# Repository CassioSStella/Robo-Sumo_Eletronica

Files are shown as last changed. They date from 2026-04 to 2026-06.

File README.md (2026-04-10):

markdown# 🤖 PatoBots — Eletrônica do Robô de Sumô

Repositório da seção de eletrônica para o desenvolvimento de um robô de sumô híbrido de 500g,
desenvolvido como atividade de trainee da equipe **PatoBots**.

---

## 📋 Sobre o Projeto

O projeto consiste no desenvolvimento do hardware eletrônico do robô, incluindo esquemáticos
e layout de PCB produzidos no **KiCad**. A especificação completa do projeto está disponível
na documentação da equipe no Notion:

🔗 [Projeto de Integração Trainees PatoBots — Sumô Híbrido 500g](https://www.notion.so/Projeto-de-Integra-o-Trainees-PatoBots-Desenvolvimento-de-Sum-H-brido-500g-327fba90dc5980c68d72c41331cd149f)

## 🚀 Como Começar

### Configuração do KiCad
Caso não tenha experiência com o KiCad, recomenda-se seguir a playlist introdutória:

🎬 [Playlist — Introdução ao KiCad](https://www.youtube.com/watch?v=tVLF8Y9jc6o&list=PL8kCnofYYWZrkhUis1svLGux1tjYNJy2Z)

### Importando componentes do SnapEDA
Para adicionar os modelos de símbolos e footprints baixados do SnapEDA ao KiCad:

🎬 [Como configurar arquivos do SnapEDA no KiCad](https://www.youtube.com/watch?v=W9cLnIjvybo)

---

## 📌 Referências

| Recurso | Descrição |
|---|---|
| [Dory — Project Neon](https://github.com/project-neon/Dory) | Robô de sumô com eletrônica feita em KiCad, usado como referência comparativa. Os modelos KiCad do Kit ESP32 Doit foram obtidos deste repositório. |

---

## 🛠️ Ferramentas Utilizadas

- [KiCad](https://www.kicad.org/) — EDA para esquemáticos e PCB
- [SnapEDA](https://www.snapeda.com/) — Biblioteca de componentes

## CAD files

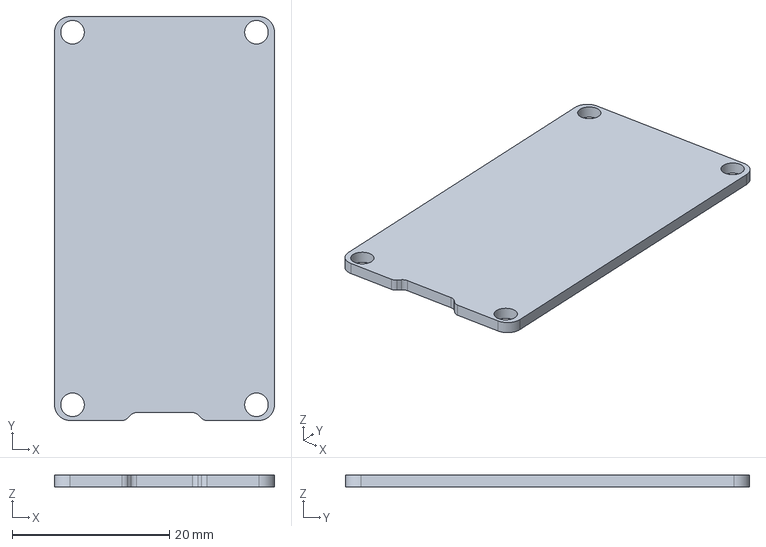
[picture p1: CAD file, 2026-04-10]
Recursos_Kicad/esp32_devkit_v1_doit.step
28.0 x 51.4 x 1.50 mm

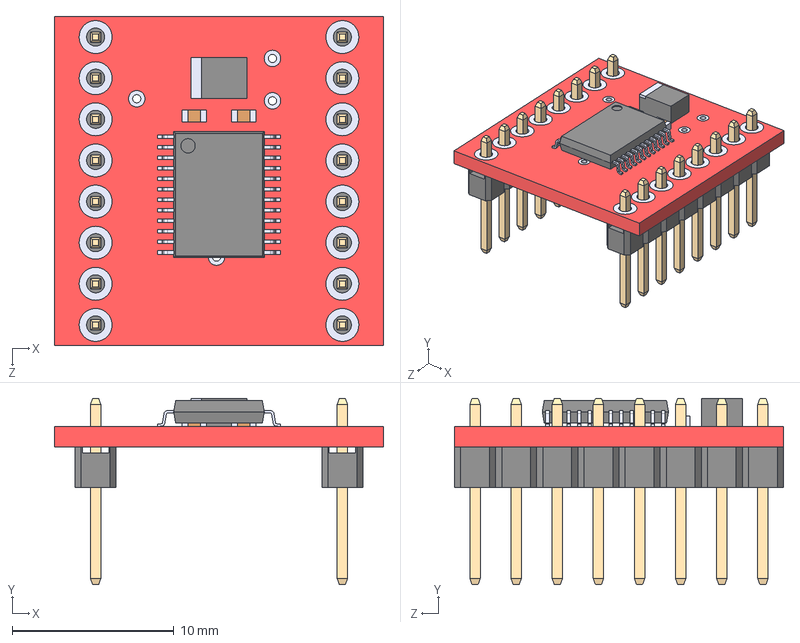
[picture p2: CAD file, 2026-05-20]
Recursos_Kicad/ROB-14450/ROB-14450--3DModel-STEP-418109.STEP
20.3 x 11.5 x 20.3 mm

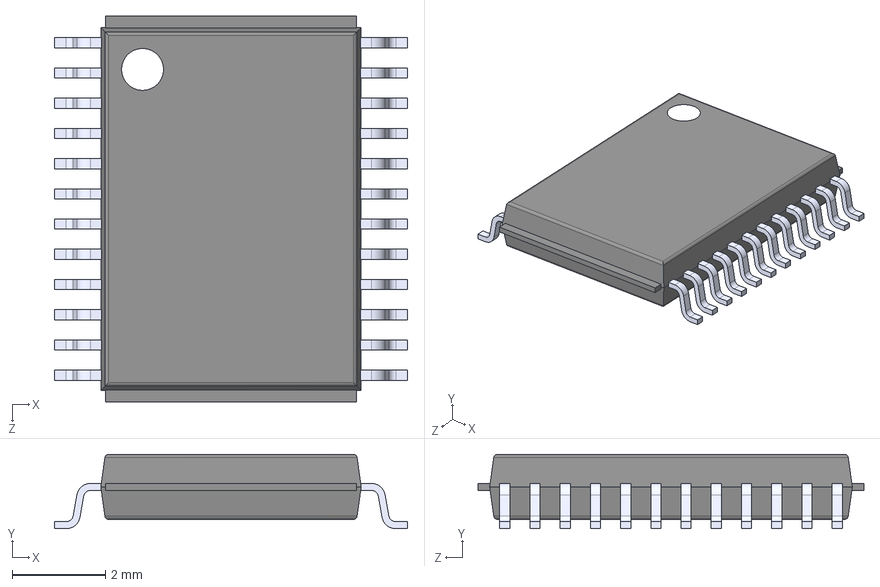
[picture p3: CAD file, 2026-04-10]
Recursos_Kicad/TB6612FNG_C_8_EL/TB6612FNG_C_8_EL.step
7.60 x 1.60 x 8.30 mm

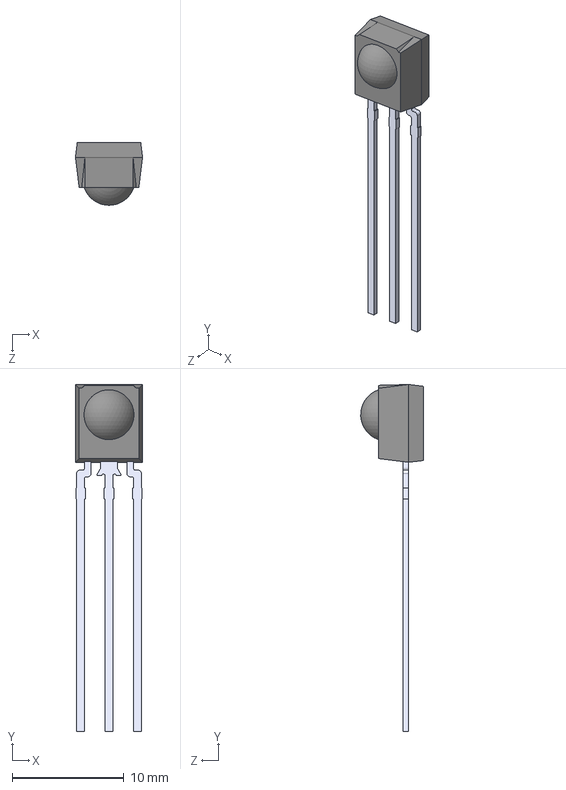
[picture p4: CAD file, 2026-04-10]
Recursos_Kicad/TSOP1838/TSOP1838.step
6.00 x 31.0 x 5.59 mm

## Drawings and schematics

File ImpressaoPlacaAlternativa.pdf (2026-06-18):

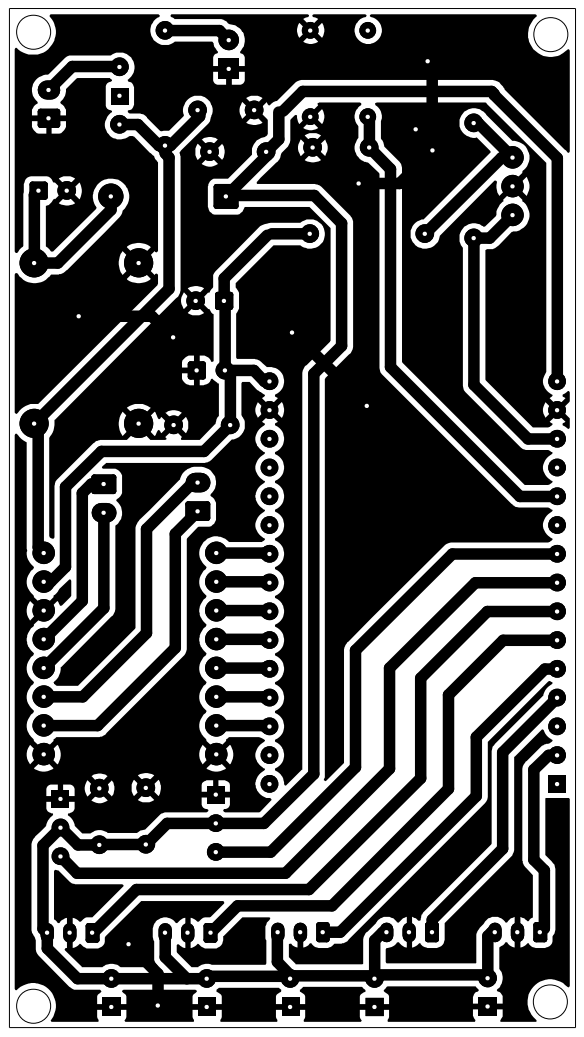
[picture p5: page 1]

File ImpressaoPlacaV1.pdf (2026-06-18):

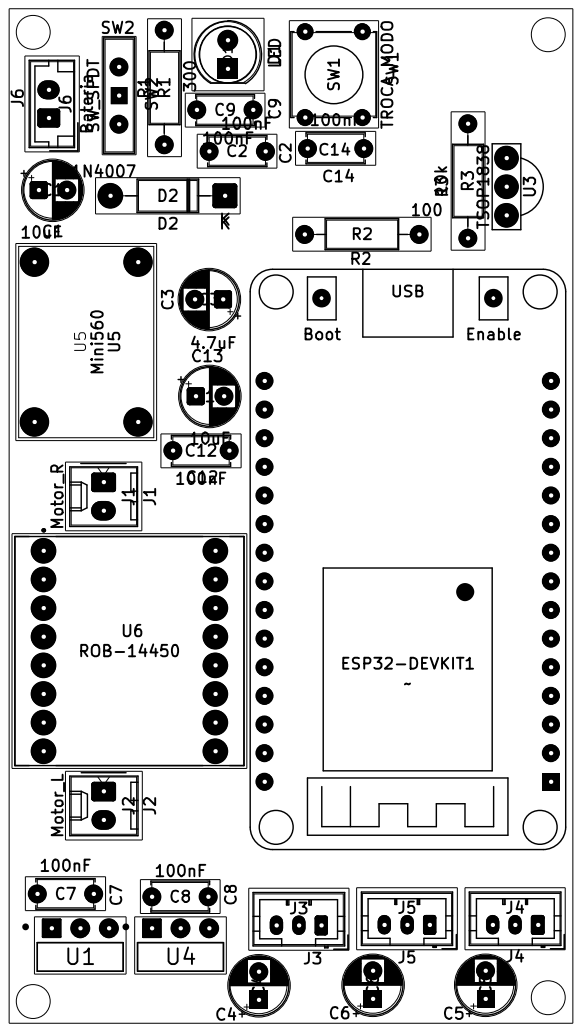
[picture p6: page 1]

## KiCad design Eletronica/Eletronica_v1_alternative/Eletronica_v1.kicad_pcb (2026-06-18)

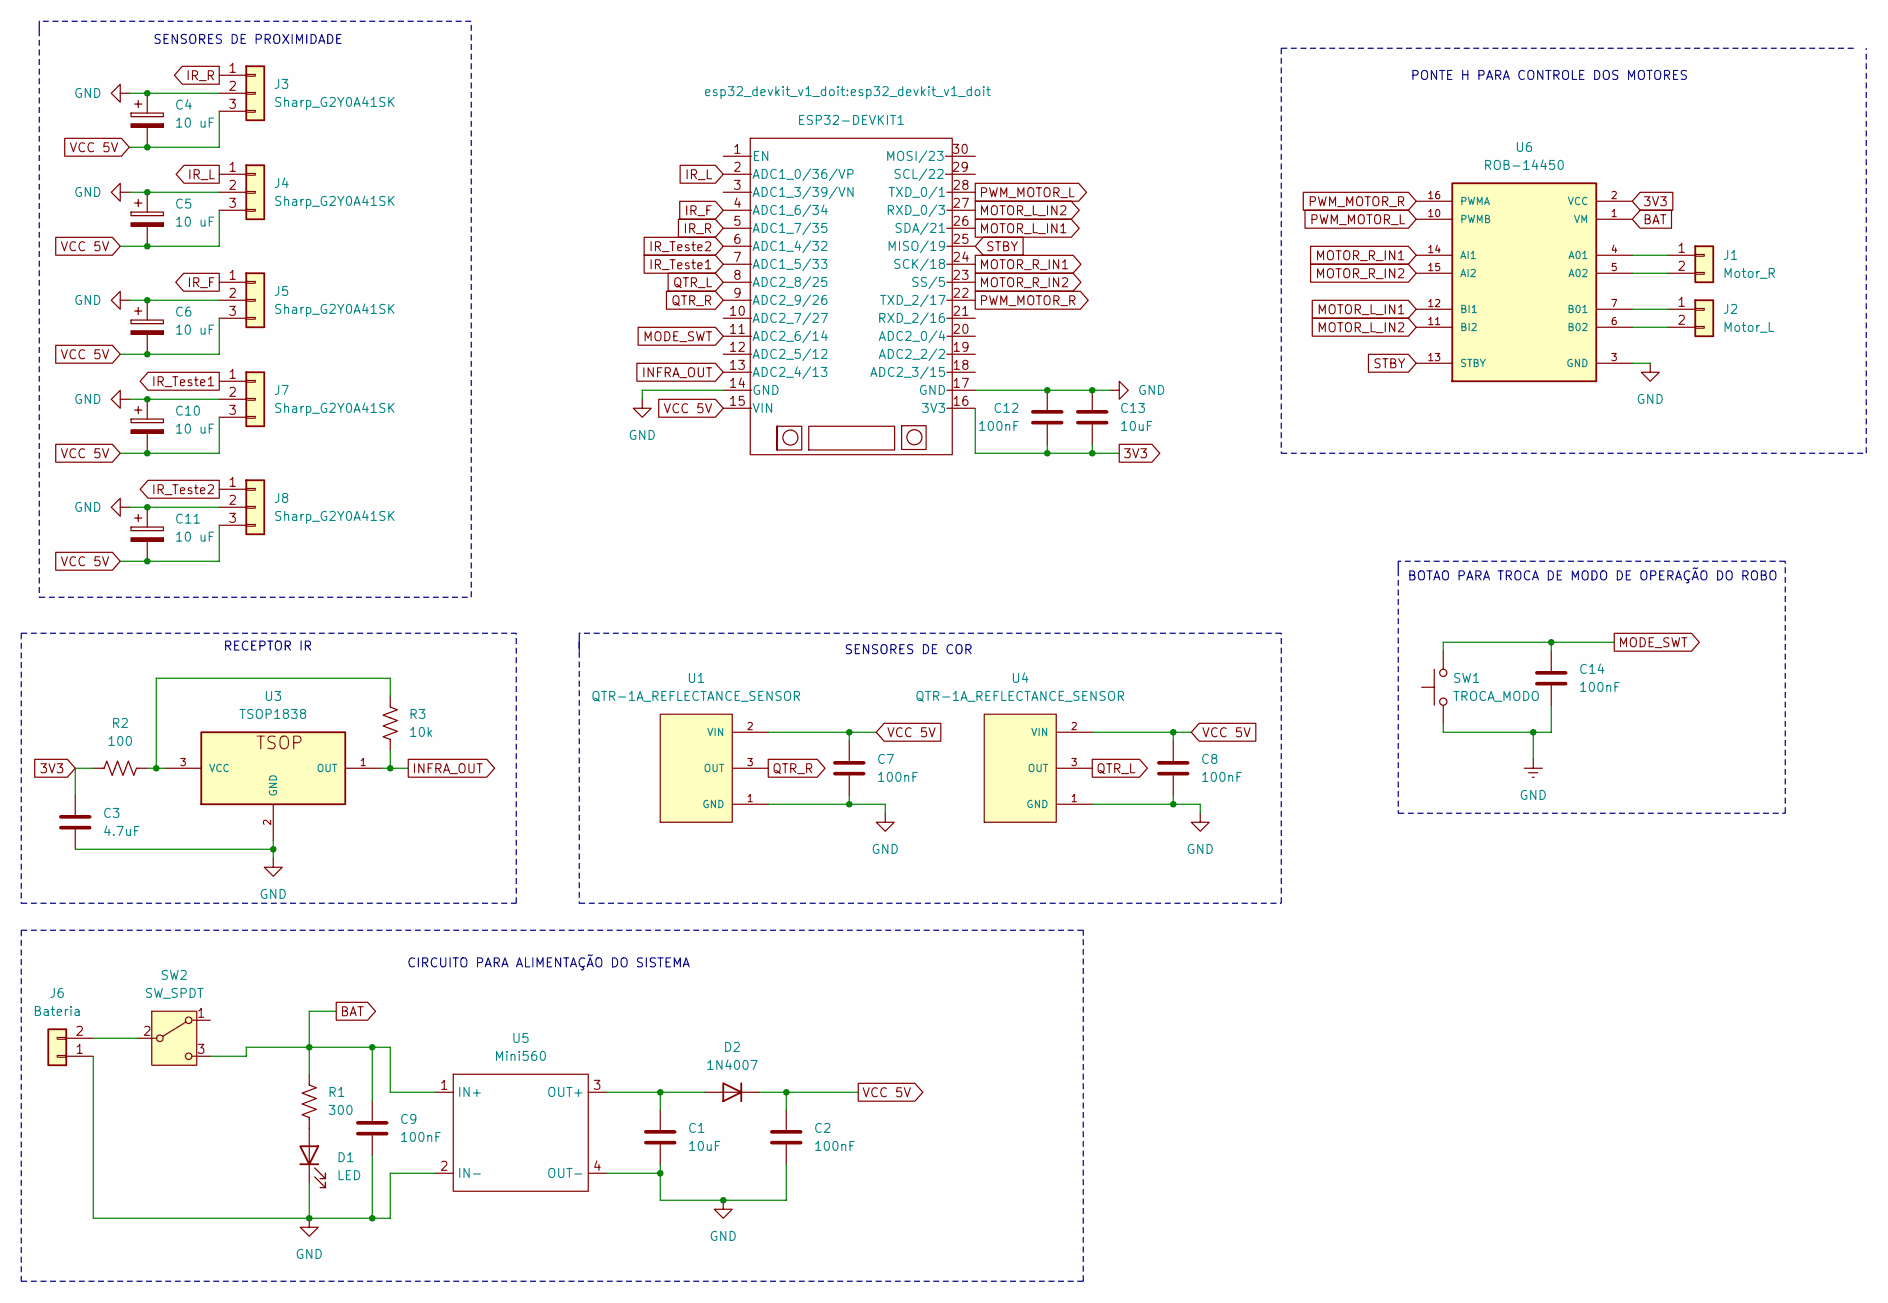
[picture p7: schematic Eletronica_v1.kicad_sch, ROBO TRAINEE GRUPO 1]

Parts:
C1, C13: 10uF; CP_Radial_D5.0mm_P2.50mm
C2, C7, C8, C9, C12, C14: 100nF; C_Disc_D5.0mm_W2.5mm_P5.00mm
C3: 4.7uF; CP_Radial_D5.0mm_P2.50mm
C4, C5, C6, C10, C11: 10 uF; CP_Radial_D5.0mm_P2.50mm
D1: LED; LED_D5.0mm
D2: 1N4007; D_DO-41_SOD81_P10.16mm_Horizontal
ESP32-DEVKIT1: esp32_devkit_v1_doit
J1: Motor_R; Molex_KK-254_AE-6410-02A_1x02_P2.54mm_Vertical
J2: Motor_L; Molex_KK-254_AE-6410-02A_1x02_P2.54mm_Vertical
J3, J4, J5, J7, J8: Sharp_G2Y0A41SK; JST_PH_B3B-PH-K_1x03_P2.00mm_Vertical
J6: Bateria; JST_EH_B2B-EH-A_1x02_P2.50mm_Vertical
R1: 300; R_Axial_DIN0207_L6.3mm_D2.5mm_P10.16mm_Horizontal
R2: 100; R_Axial_DIN0207_L6.3mm_D2.5mm_P10.16mm_Horizontal
R3: 10k; R_Axial_DIN0207_L6.3mm_D2.5mm_P10.16mm_Horizontal
SW1: TROCA_MODO; SW_Tactile_Straight_KSA0Axx1LFTR
SW2: SW_SPDT; SW_Slide-03_Wuerth-WS-SLTV_10x2.5x6.4_P2.54mm
U1, U4: QTR-1A_REFLECTANCE_SENSOR; SENSOR_QTR-1A_REFLECTANCE_SENSOR
U3: TSOP1838
U5: Mini560; Sem título
U6: ROB-14450; MODULE_ROB-14450; PARTREV 11-13-17

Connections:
3V3: C3.1, C12.2, C13.2, ESP32-DEVKIT1.16 (3V3), R2.1, U6.2 (VCC)
BAT: C9.1, R1.1, SW2.3 (C), U5.1 (IN+), U6.1 (VM)
GND: C1.2, C2.2, C3.2, C4.1, C5.1, C6.1, C7.2, C8.2, C9.2, C10.1, C11.1, C12.1, C13.1, C14.2, D1.1 (K), ESP32-DEVKIT1.14 (GND), ESP32-DEVKIT1.17 (GND), J3.2, J4.2, J5.2, J6.1, J7.2, J8.2, SW1.1, U1.1 (GND), U3.2 (GND), U4.1 (GND), U5.2 (IN-), U5.4 (OUT-), U6.3 (GND), U6.8 (GND), U6.9 (GND)
INFRA_OUT: ESP32-DEVKIT1.13 (ADC2_4/13), R3.2, U3.1 (OUT)
IR_F: ESP32-DEVKIT1.4 (ADC1_6/34), J5.1
IR_L: ESP32-DEVKIT1.2 (ADC1_0/36/VP), J4.1
IR_R: ESP32-DEVKIT1.5 (ADC1_7/35), J3.1
IR_Teste1: ESP32-DEVKIT1.7 (ADC1_5/33), J7.1
IR_Teste2: ESP32-DEVKIT1.6 (ADC1_4/32), J8.1
MODE_SWT: C14.1, ESP32-DEVKIT1.11 (ADC2_6/14), SW1.2
MOTOR_L_IN1: ESP32-DEVKIT1.26 (SDA/21), U6.12 (BI1)
MOTOR_L_IN2: ESP32-DEVKIT1.27 (RXD_0/3), U6.11 (BI2)
MOTOR_R_IN1: ESP32-DEVKIT1.24 (SCK/18), U6.14 (AI1)
MOTOR_R_IN2: ESP32-DEVKIT1.23 (SS/5), U6.15 (AI2)
unnamed: D1.2 (A), R1.2
unnamed: C1.1, D2.2 (A), U5.3 (OUT+)
unnamed: J1.1, U6.4 (A01)
unnamed: J1.2, U6.5 (A02)
unnamed: J2.1, U6.7 (B01)
unnamed: J2.2, U6.6 (B02)
unnamed: J6.2, SW2.2 (B)
unnamed: R2.2, R3.1, U3.3 (VCC)
PWM_MOTOR_L: ESP32-DEVKIT1.28 (TXD_0/1), U6.10 (PWMB)
PWM_MOTOR_R: ESP32-DEVKIT1.22 (TXD_2/17), U6.16 (PWMA)
QTR_L: ESP32-DEVKIT1.8 (ADC2_8/25), U4.3 (OUT)
QTR_R: ESP32-DEVKIT1.9 (ADC2_9/26), U1.3 (OUT)
STBY: ESP32-DEVKIT1.25 (MISO/19), U6.13 (STBY)
VCC 5V: C2.1, C4.2, C5.2, C6.2, C7.1, C8.1, C10.2, C11.2, D2.1 (K), ESP32-DEVKIT1.15 (VIN), J3.3, J4.3, J5.3, J7.3, J8.3, U1.2 (VIN), U4.2 (VIN)

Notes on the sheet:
PONTE H PARA CONTROLE DOS MOTORES
BOTAO PARA TROCA DE MODO DE OPERAÇÃO DO ROBO
SENSORES DE COR
SENSORES DE PROXIMIDADE
CIRCUITO PARA ALIMENTAÇÃO DO SISTEMA
RECEPTOR IR

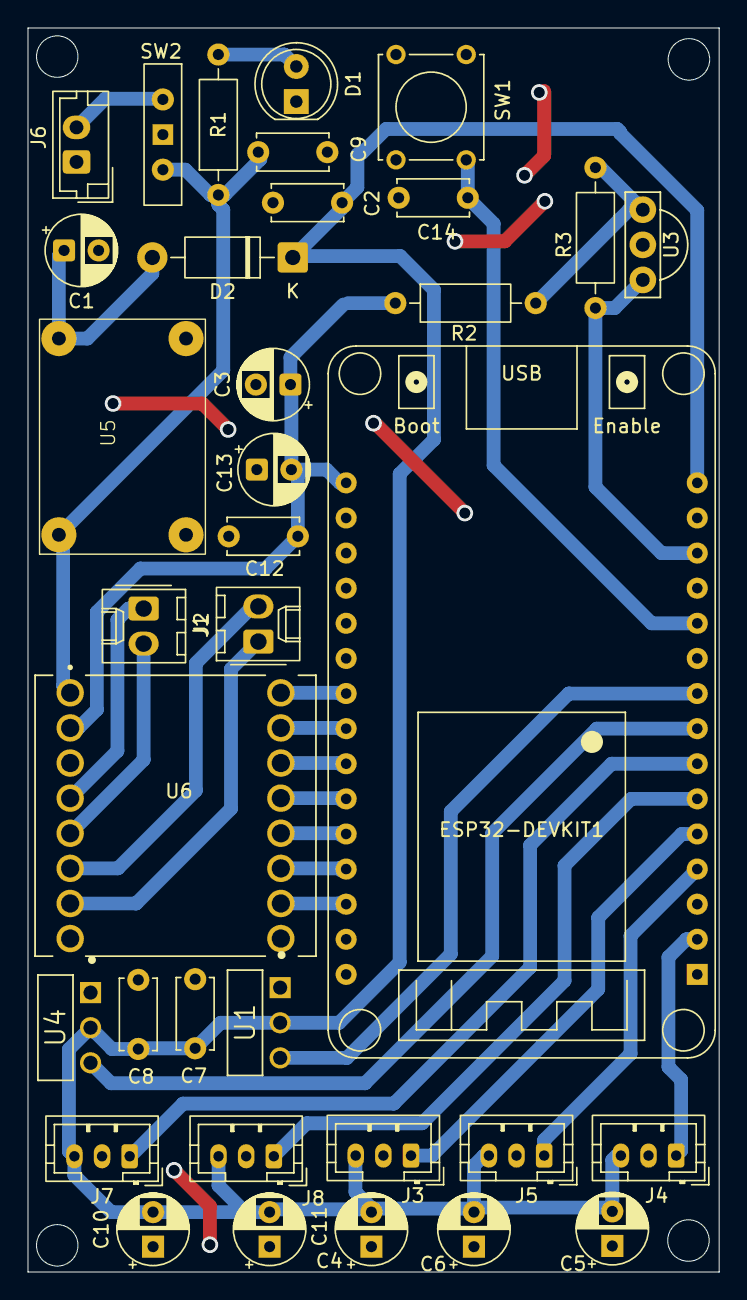
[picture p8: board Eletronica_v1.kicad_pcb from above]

Board: 2 copper layers, 50.0 x 90.0 mm, 35 parts (0 on the bottom side), 28 nets.

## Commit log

2026-04-10 Estrutura inicial da etapa de eletroncia
    [Eletronica_v1.kicad_pcb, Eletronica_v1.kicad_sch, TB6612FNG_C_8_EL.step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]
2026-04-24 Corrigido circuito de alimentação e conexão dos periféricos
    [Eletronica_v1.kicad_pcb, Eletronica_v1.kicad_sch]
2026-05-20 Atualizado swtich e footprints
    [Eletronica_v1.kicad_pcb, Eletronica_v1.kicad_sch, ROB-14450--3DModel-STEP-418109.STEP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]
2026-05-29 Reduzido Capacitores, e tracado layout parcial da pcb
    [Eletronica_v1.kicad_pcb, Eletronica_v1.kicad_sch]
2026-06-18 Finalizado a versao funcional da placa
    [Eletronica_v1.kicad_pcb, Eletronica_v1.kicad_sch]
2026-06-18 Nova placa alternativa com 2 sensores sharp adicionais
    [Eletronica_v1.kicad_pcb, Eletronica_v1.kicad_sch]
